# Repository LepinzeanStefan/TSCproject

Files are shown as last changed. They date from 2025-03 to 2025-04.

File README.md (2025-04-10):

# 1. Diagrama Bloc
Diagrama de mai jos arata fluxul de alimentare si conectivitatile principale intre componentele proiectului:
```mermaid
flowchart TD
    %% Blocul de alimentare
    A[USB-C Connector & ESD Protection] 
    B[Li-Po Battery]
    C[Battery Charging Controller<br>MCP73831]
    D[LDO Voltage Regulator]

    %% Blocul de procesare si memorie
    E[ESP32-C6-WROOM-1-N8]
    F[External NOR Flash 64MB]
    G[RTC Module<br>DS3231SN]
    
    %% Blocul de senzori si interfete
    H[Environmental Sensor<br>BME688]
    I[Qwiic / Stemma QT Interface]
    
    %% Blocul de afisare
    J[E-Paper Display Drive Circuit]
    K[E-Paper Display Header<br>Type Selector]
    
    %% Blocul de stocare si management
    L[SD Card]
    M[Voltage Supervisor<br>Reset/Boot Button]

    %% Conexiuni Power Supply
    A --> D
    A --> C
    C --> B
    D --> E

    %% Conexiuni pe placa de dezvoltare
    E --> F
    E --> G
    E --> H
    H --> I

    E --> J
    J --> K

    E --> L
    E --> M
```

# 2. Functionalitate Hardware
===========================

### 2.1 Module, Componente si Senzori

**ESP32-C6-WROOM-1-N8**

- **Rol**: Microcontroler principal, coordoneaza comunicarile (SPI, I2C, UART etc.), citirea senzorilor si controlul perifericelor.

**USB-C Connector & ESD Protection**

- **Rol**: Permite alimentarea prin USB-C si asigura protectie la descarcari electrostatice.

**Battery Charging Controller (MCP73831)**

- **Rol**: Incarca bateria Li-Po si gestioneaza curentul de incarcare.

**Li-Po Battery**

- **Rol**: Sursa de alimentare secundara, permite functionarea sistemului fara USB.

**LDO Voltage Regulator**

- **Rol**: Stabilizeaza tensiunea de 3.3V pentru ESP32-C6 si alte componente.

**External NOR Flash 64MB**

- **Rol**: Memorie suplimentara pentru stocarea datelor si a firmware-ului.

**RTC Module (DS3231SN)**

- **Rol**: Furnizeaza ceas de timp real (Real-Time Clock) cu mare acuratete.
- **Interfata**: I2C, cu suport pentru alarme si detectie a pierderii de tensiune (baterie backup).

**Environmental Sensor (BME688)**

- **Rol**: Masoara temperatura, umiditatea, presiunea si calitatea aerului (VOC).
- **Interfata**: I2C, consum redus in modul standby, integreaza un senzor de gaze.
- **Integrare**: Foloseste Qwiic / Stemma QT pentru conectare rapida.

**E-Paper Display Drive Circuit si Header**

- **Rol**: Genereaza semnalele necesare pentru controlul unui ecran E-Paper si permite selectarea tipului de display.
- **Interfata**: SPI, cu linii de control dedicate (Busy, Reset, DC, CS).

**SD Card**

- **Rol**: Stocare locala de date, fisiere de configurare sau inregistrari pe termen lung.
- **Interfata**: SPI, cu linii separate de chip select.

**Voltage Supervisor + Reset/Boot Button**

- **Rol**: Monitorizeaza tensiunea de alimentare si gestioneaza semnalele de reset si boot pentru ESP32-C6.

### 2.2 Specificatii de Comunicare

- **I2C**: Folosit pentru BME688 si DS3231SN.
- **SPI**: Folosit pentru NOR Flash, E-Paper Display si SD Card.
- **UART**: Disponibil pentru debug sau alte module optionale.
- **Wi-Fi si Bluetooth LE**: Furnizate de ESP32-C6.

### 2.3 Procesare si Calcule de Consum de Energie

- **ESP32-C6**:
  - Consum in mod activ: ~80-240 mA (in functie de sarcina Wi-Fi/BT).
  - Consum in mod sleep: <1 mA (mod deep sleep).

- **BME688**:
  - Consum tipic: ~2.1 uA in sleep, pana la ~3.1 mA in mod activ.

- **NOR Flash**:
  - Consum in citire/scriere: 5-15 mA, in standby: <10 uA.

- **DS3231SN**:
  - Consum: ~150 uA cu backup la baterie.

- **LDO**:
  - Eficienta depinde de diferenta de tensiune (Vin - 3.3V) si curentul total.

In functie de scenariul de utilizare, modul sleep al ESP32-C6 si senzorii in standby reduc semnificativ consumul. Bateria Li-Po poate sustine sistemul pentru ore sau chiar zile, in functie de capacitate si de cat de des se activeaza comunicarile Wi-Fi/BT.

# 3. Pini ESP32-C6 si Motivatii
=============================

In tabelul de mai jos sunt prezentate pinii principali ai ESP32-C6 si rolul lor in proiect:

| Pin ESP32-C6 | Componenta / Rol | Motivatie |
|---|---|---|
| IO14 (SDA) | I2C SDA catre BME688 si DS3231SN | Linia de date pentru I2C |
| IO15 (SCL) | I2C SCL catre BME688 si DS3231SN | Semnal de clock I2C |
| IO6 (MOSI) | SPI MOSI catre NOR Flash, E-Paper, SD Card | Transfer date catre periferice SPI |
| IO7 (MISO) | SPI MISO din NOR Flash, E-Paper, SD Card  | Primire date de la periferice SPI |
| IO8 (SCK) | SPI Clock | Semnal de clock SPI |
| IO9 (CS1) | Chip Select NOR Flash | Control dedicat pentru NOR Flash |
| IO10 (CS2) | Chip Select E-Paper Display | Control dedicat pentru Display |
| IO11 (CS3) | Chip Select SD Card | Control dedicat pentru SD Card |
| IO16, IO17 | UART RX, TX (debug) | Debug serial si programare |
| IO21 | Reset/Boot control | Butoane de reset si boot |

# 4. Bill of Materials (BOM)
=============================

| Component | Buy | Datasheet |
| --- | --- | --- |
| PFMF.050.1 | [Retailer](https://ro.mouser.com/ProductDetail/Schurter/PFMF.050.2?qs=1auRipcfynCums5v1iucSA%3D%3D) |  [Datasheet](https://ro.mouser.com/datasheet/2/358/typ_PFMF-1275918.pdf) |
| USB4110-GF-A | [Retailer](https://ro.mouser.com/ProductDetail/GCT/USB4110-GF-A?qs=KUoIvG%2F9IlYiZvIXQjyJeA%3D%3D) | [Datasheet](https://ro.mouser.com/datasheet/2/837/GCT_USB4110_Product_Drawing___20k_cycles-3455479.pdf) |
| USBLC6-2SC6Y | [Retailer](https://ro.mouser.com/ProductDetail/STMicroelectronics/USBLC6-2SC6Y?qs=gNDSiZmRJS%2FOgDexvXkdow%3D%3D) | [Datasheet](https://ro.mouser.com/datasheet/2/389/usblc6_2sc6y-1852505.pdf) |
| SD0805S020S1R0 | [Retailer](https://ro.mouser.com/ProductDetail/KYOCERA-AVX/SD0805S020S1R0?qs=jCA%252BPfw4LHbpkAoSnwrdjw%3D%3D) | [Datasheet](https://ro.mouser.com/datasheet/2/40/schottky-3165252.pdf) |
| DMG2305UX-7 | [Retailer](https://ro.mouser.com/ProductDetail/Diodes-Incorporated/DMG2305UX-7?qs=L1DZKBg7t5F%2FNBHrjfxC%252Bg%3D%3D) | [Datasheet](https://www.diodes.com/assets/Datasheets/DMG2305UX.pdf) |
| XC6220A331MR-G | [Retailer](https://ro.mouser.com/ProductDetail/Torex-Semiconductor/XC6220A331MR-G?qs=AsjdqWjXhJ8ZSWznL1J0gg%3D%3D) | [Datasheet](https://ro.mouser.com/datasheet/2/760/xc6220-3371556.pdf) |
| Condensator 100 uF TANT | [Retailer](https://ro.mouser.com/ProductDetail/KYOCERA-AVX/TAJW107M010RNJ?qs=Wtp%252Bf%2FAeVqIH8v1VxV%252B1Rg%3D%3D) | [Datasheet](https://ro.mouser.com/datasheet/2/40/TAJ-3165264.pdf) |
| 112A-TAAR-R03_ATTEND | [Retailer](https://www.digikey.ro/en/products/detail/attend-technology/112A-TAAR-R03/17633923) | [Datasheet](https://www.attend.com.tw/data/download/file/112A-TAAR-R03_Spec.pdf)
| ESP32-C6-WROOM-1-N8 | [Retailer](https://ro.mouser.com/ProductDetail/Espressif-Systems/ESP32-C6-WROOM-1-N8?qs=8Wlm6%252BaMh8ST02Gmwp74cw%3D%3D) | [Datasheet](https://ro.mouser.com/datasheet/2/891/Espressif_ESP32_C6_WROOM_1__Datasheet_V0_1_PRELIMI-3239987.pdf) |
| MCP73831 | [Retailer](https://ro.mouser.com/ProductDetail/Microchip-Technology/MCP73831T-2ACI-OT?qs=yUQqVecv4qvbBQBGbHx0Mw%3D%3D) | [Datasheet](https://ro.mouser.com/datasheet/2/268/MCP73831_Family_Data_Sheet_DS20001984H-3441711.pdf) |
| CHG_LED | [Retailer](https://store.comet.srl.ro/Catalogue/Product/40478/) | [Datasheet](https://www.snapeda.com/parts/KP-1608SURCK/Kingbright/datasheet/) |
| SI1308EDL-T1-GE3 | [Retailer](https://ro.mouser.com/ProductDetail/Vishay-Semiconductors/SI1308EDL-T1-GE3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) | [Datasheet](https://www.vishay.com/doc?63399) |
| MBR0530 | [Retailer](https://ro.mouser.com/ProductDetail/Micro-Commercial-Components-MCC/MBR0530-T?qs=9VyI4qLX4NTSXkb9ynzJnA%3D%3D) | [Datasheet](https://ro.mouser.com/datasheet/2/258/mcc_mbr0520~mbr0560sod123-1179695.pdf) |
| L1 | [Retailer](https://ro.mouser.com/ProductDetail/Wurth-Elektronik/744043680?qs=PGXP4M47uW6VkZq%252BkzjrHA%3D%3D) | [Datasheet](https://www.we-online.com/components/products/datasheet/744043680.pdf) |
| FH34SRJ-24S-0.5SH_99_ | [Retailer](https://ro.mouser.com/ProductDetail/Hirose-Connector/FH34SRJ-24S-0.5SH99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) | [Datasheet](https://ro.mouser.com/datasheet/2/185/FH34SRJ_24S_0_5SH_99__CL0580_1255_6_99_2DDrawing_0-1615044.pdf) |
| BME688 | [Retailer](https://ro.mouser.com/ProductDetail/Bosch-Sensortec/BME688?qs=IS%252B4QmGtzzqQoVDscqwx3A%3D%3D) | [Datasheet](https://ro.mouser.com/datasheet/2/783/bst_bme688_fl000-2307034.pdf) |
| BD5229G-TR | [Retailer](https://ro.mouser.com/ProductDetail/ROHM-Semiconductor/BD5229G-TR?qs=4kLU8WoGk0vvnhrrYwdszw%3D%3D) | [Datasheet](https://fscdn.rohm.com/en/products/databook/datasheet/ic/power/voltage_detector/bd52xxg-e.pdf) |
| Button | [Retailer](https://ro.mouser.com/ProductDetail/CK/KMR221GULCLFS?qs=u2NJ%252B70r0goBXaNk7IrU0Q%3D%3D) | [Datasheet](https://www.ckswitches.com/media/1479/kmr2.pdf) |
| MAX17048G+T10 | [Retailer](https://ro.mouser.com/ProductDetail/Analog-Devices-Maxim-Integrated/MAX17048G%2bT10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) | [Datasheet](https://ro.mouser.com/datasheet/2/609/MAX17048_MAX17049-3469099.pdf) |
| W25Q512JVEIQ | [Retailer](https://ro.mouser.com/ProductDetail/Winbond/W25Q512JVEIQ?qs=l7cgNqFNU1jw6svr3at6tA%3D%3D) | [Datasheet](https://ro.mouser.com/datasheet/2/949/Winbond_W25Q512JV_Datasheet-3240039.pdf) |
| PGB1010603MR | [Retailer](https://ro.mouser.com/ProductDetail/Littelfuse/PGB1010603MRHF?qs=KvZd0dN2Zg%2FuIq6icj%252BGKA%3D%3D) | [Datasheet](https://www.littelfuse.com/media?itemid=8a337998-d54d-466b-be4e-dc5bcd1f9321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) |
| QWIIC_RIGHT_ANGLE | [Retailer](https://ro.mouser.com/ProductDetail/GCT/USB4110-GF-A?qs=KUoIvG%2F9IlYiZvIXQjyJeA%3D%3D) | [Datasheet](https://ro.mouser.com/datasheet/2/837/GCT_USB4110_Product_Drawing___20k_cycles-3455479.pdf) |
| DS3231SN# | [Retailer](https://ro.mouser.com/ProductDetail/Analog-Devices-Maxim-Integrated/DS3231SN?qs=ffX8NcjNb2RmKAb9wAk9Ug%3D%3D) | [Datasheet](https://ro.mouser.com/datasheet/2/609/DS3231-3421123.pdf) |
| CPH3225A C10_SUPERCAP | [Retailer](https://ro.mouser.com/ProductDetail/Seiko-Semiconductors/CPH3225A?qs=3etwrb1wR%252BhUOph6lAO7eg%3D%3D) | [Datasheet](https://ro.mouser.com/datasheet/2/360/Seiko_Instruments_MicroBattery_E_20230330_2024Jan_-3561061.pdf) |
| Condensator 100nF | [Retailer](https://ro.mouser.com/ProductDetail/KYOCERA-AVX/06033G104ZAT2A?qs=NXubJDmysXJMPmHfVo6Z%252BA%3D%3D) | [Datasheet](https://ro.mouser.com/datasheet/2/40/KGM_Y5V-3223189.pdf) |
| Condensator 4.7uF | [Retailer](https://ro.mouser.com/ProductDetail/KYOCERA-AVX/0402ZD475MAT2A?qs=NBFAU1oqP4W4U2PCPHI0sg%3D%3D) | [Datasheet](https://ro.mouser.com/datasheet/2/40/cx5r_KGM-3223198.pdf) |
| Condensator 10uF | [Retailer](https://ro.mouser.com/ProductDetail/Samsung-Electro-Mechanics/CL10A106KQ8NNNL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) | [Datasheet](https://ro.mouser.com/datasheet/2/585/MLCC-1837944.pdf) |
| Condensator 1uF/50V | [Retailer](https://ro.mouser.com/ProductDetail/KYOCERA-AVX/06035D105MAT2A?qs=k4kUdCzLgS5%252BURKe1SOIeQ%3D%3D) | [Datasheet](https://ro.mouser.com/datasheet/2/40/cx5r_KGM-3223198.pdf) |
| Resistor 10K | [Retailer](https://ro.mouser.com/ProductDetail/Vishay-Beyschlag/MCS0402MD1002BE000?qs=17u8i%2FzlE8%2F9BrAaXkMk1w%3D%3D) | [Datasheet](https://www.vishay.com/doc?28952) |
| Resistor 200 | [Retailer](https://ro.mouser.com/ProductDetail/Vishay-Beyschlag/MCS0402MD2000BE100?qs=3SvaY9RawMJNVte4F12%252BZQ%3D%3D) | [Datasheet](https://www.vishay.com/doc?28952) |
| Resistor 100K | [Retailer](https://ro.mouser.com/ProductDetail/Vishay-Beyschlag/MCT0603PD1003DP500?qs=5aG0NVq1C4wWAn8Ei3OpZA%3D%3D) | [Datasheet](https://www.vishay.com/doc?28916) |
| Resistor 2.2 | [Retailer](https://ro.mouser.com/ProductDetail/SEI-Stackpole/RMCF0402FT2R20?qs=IPgv5n7u5QbBgyl0jwhwsA%3D%3D) | [Datasheet](https://ro.mouser.com/datasheet/2/385/SEI_RMCF_RMCP-3077565.pdf) |
| Resistor 5K1| [Retailer](https://www.venkel.com/part/TFCR0603-16W-K-5690FT) | [Datasheet](https://data.venkel.com/documents/tfcr-series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.) |
| Resistor 2K | [Retailer](https://ro.mouser.com/ProductDetail/Vishay-Beyschlag/MCS04020C2001FE000?qs=wTZ%2FFzl837YG0wIkZJJOwQ%3D%3D) | [Datasheet](https://www.vishay.com/doc?28705) |
| Resistor 0.47 | [Retailer](https://ro.mouser.com/ProductDetail/SEI-Stackpole/CSR0402JKR470?qs=IPgv5n7u5QawIB6nBEt8wA%3D%3D) | [Datasheet](https://ro.mouser.com/datasheet/2/385/SEI_CSR_CSRN-3077593.pdf) |
| Resistor 15 | [Retailer](https://ro.mouser.com/ProductDetail/YAGEO/RT0402FRE0715RL?qs=BXCcY9r%252B08DFFpLSkPOIqQ%3D%3D) | [Datasheet](https://ro.mouser.com/datasheet/2/447/PYu_RT_1_to_0_01_RoHS_L_15-3461507.pdf) |

# 5. Alte Informatii Relevante
=============================

### 5.1 Design Log si Randari PCB

**Randari PCB**:

- Exista randari 3D ale PCB-ului care arata pozitionarea componentelor majore: conectorul USB-C, ESP32-C6, senzorii si conectorii.
- Carcasa este proiectata in Fusion 360.

### 5.2 Asezarea Componentelor in Carcasa

- Bateria Li-Po este plasata in jurul PCB-ului pentru a economisi spatiu.
- Conectorii Qwiic / Stemma QT sunt pozitionati in marginea placii pentru a permite atasarea rapida a altor senzori.
- Microcontrolerul ESP36 a fost plasat la marginea PCB-ului pentru a reduce pe cat posibil interferentele la antena. Din acelasi motiv a fost taiat si planul de masa si placa PCB in jurul antenei.

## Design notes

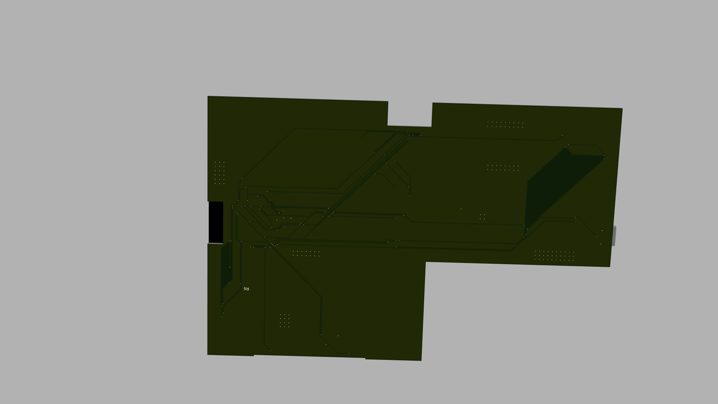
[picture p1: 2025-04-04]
Images/OpenBook v6.png

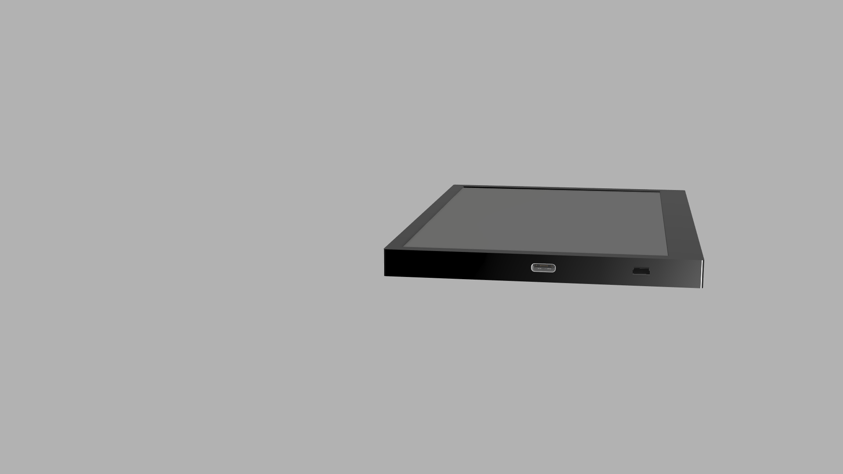
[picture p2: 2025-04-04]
Images/OpenBook Enclosure v7.png

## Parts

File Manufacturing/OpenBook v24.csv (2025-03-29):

Qty | Value | Device | Package | Parts | Description | ARROW_PART_NUMBER | ARROW_PRICE-STOCK | AVAILABILITY | BOOT_BUTTON | CENTROID_NOT_SPECIFIED | CHANGE_BUTTON | CHECK_PRICES | COPYRIGHT | DATASHEET | DESCRIPTION | DIGIKEY_DESCRIPTION | DIGIKEY_PART_NUMBER | DMG2305UX-7 | HEIGHT | LEAD_FREE | MANUFACTURER_NAME | MANUFACTURER_PART_NUMBER | MF | MFR_NAME | MOUSER_PART_NUMBER | MOUSER_PRICE-STOCK | MOUSER_TESTING_PART_NUMBER | MOUSER_TESTING_PRICE-STOCK | MP | MPN | PACKAGE | POPULARITY | PREFIX | PRICE | PROD_ID | PURCHASE-URL | RESET_BUTTON | ROHS | SNAPEDA_LINK | SPICEMODEL | SPICEPREFIX | TEMPERATURE_RANGE_HIGH | TEMPERATURE_RANGE_LOW | TP_SIGNAL_NAME | VALUE
1 |  | SJ | SJ | SJ1 | SMD solder JUMPER |  |  |  |  |  |  |  |  |  |  |  |  |  |  |  |  |  |  |  |  |  |  |  |  |  |  | 3
1 | 0.1uF/50V | EAGLE-LTSPICE_CC0402 | EAGLE-LTSPICE_C0402 | EPD_C5 | CAPACITOR, European symbol |  |  |  |  |  |  |  |  |  |  |  |  |  |  |  |  |  |  |  |  |  |  |  |  |  |  |  |  |  |  |  |  |  |  | NONE | C
1 | 0.47 | ESP32_WROVER_EAGLE-LTSPICE_RR0402 | R0402 | R2 | RESISTOR, European symbol |  |  |  |  |  |  |  |  |  |  |  |  |  |  |  |  |  |  |  |  |  |  |  |  |  |  |  |  |  |  |  |  |  |  | NONE | R
1 | 100K | ESP32_WROVER_EAGLE-LTSPICE_RR0402 | R0402 | R1_PWRUSB | RESISTOR, European symbol |  |  |  |  |  |  |  |  |  |  |  |  |  |  |  |  |  |  |  |  |  |  |  |  |  |  |  |  |  |  |  |  |  |  | NONE | R
8 | 100nF | EAGLE-LTSPICE_CC0402 | EAGLE-LTSPICE_C0402 | C1, C1_SENS, C2_SENS, C4_USB, C6, C9, C10, C_DELAY | CAPACITOR, European symbol |  |  |  |  |  |  |  |  |  |  |  |  |  |  |  |  |  |  |  |  |  |  |  |  |  |  |  |  |  |  |  |  |  |  | NONE | C
1 | 100uF TANT | RCL_CPOL-EUCT3528 | RCL_CT3528 | C3 | POLARIZED CAPACITOR, European symbol |  |  |  |  |  |  |  |  |  |  |  |  |  |  |  |  |  |  |  |  |  |  |  |  |  |  | 0 |  |  |  |  |  |  |  |  | C
16 | 10K | ESP32_WROVER_EAGLE-LTSPICE_RR0402 | R0402 | R1, R1_PINH, R2_PINH, R3, R5, R6, R7, R8, R9, R10, R12, R13, R_BOOT, R_CHANGE, R_CL1, R_RESET | RESISTOR, European symbol |  |  |  |  |  |  |  |  |  |  |  |  |  |  |  |  |  |  |  |  |  |  |  |  |  |  |  |  |  |  |  |  |  |  | NONE | R
1 | 10uF | EAGLE-LTSPICE_CC0402 | EAGLE-LTSPICE_C0402 | C7 | CAPACITOR, European symbol |  |  |  |  |  |  |  |  |  |  |  |  |  |  |  |  |  |  |  |  |  |  |  |  |  |  |  |  |  |  |  |  |  |  | NONE | C
1 | 112A-TAAR-R03_ATTEND | 112A-TAAR-R03_ATTEND | 112ATAARR03ATTEND | J4 | Micro SD Card Socket, Push-Push Type, Top Mount, SMT, H=1.83mm, 10u |  |  |  |  |  |  |  |  |  | Micro SD Card Socket | Push-Push Type | Top Mount | SMT | H=1.83mm | 10u |  |  |  | 1.9mm |  | ATTEND | 112A-TAAR-R03 ATTEND
1 | 15 | ESP32_WROVER_EAGLE-LTSPICE_RR0402 | R0402 | R_CAPACITOR | RESISTOR, European symbol |  |  |  |  |  |  |  |  |  |  |  |  |  |  |  |  |  |  |  |  |  |  |  |  |  |  |  |  |  |  |  |  |  |  | NONE | R
1 | 1uF | EAGLE-LTSPICE_CC0402 | EAGLE-LTSPICE_C0402 | C5 | CAPACITOR, European symbol |  |  |  |  |  |  |  |  |  |  |  |  |  |  |  |  |  |  |  |  |  |  |  |  |  |  |  |  |  |  |  |  |  |  | NONE | C
9 | 1uF/50V | EAGLE-LTSPICE_CC0402 | EAGLE-LTSPICE_C0402 | EPD_C1, EPD_C2, EPD_C6, EPD_C7, EPD_C8, EPD_C9, EPD_C10, EPD_C11, EPD_C12 | CAPACITOR, European symbol |  |  |  |  |  |  |  |  |  |  |  |  |  |  |  |  |  |  |  |  |  |  |  |  |  |  |  |  |  |  |  |  |  |  | NONE | C
1 | 2.2 | ESP32_WROVER_EAGLE-LTSPICE_RR0402 | R0402 | R4 | RESISTOR, European symbol |  |  |  |  |  |  |  |  |  |  |  |  |  |  |  |  |  |  |  |  |  |  |  |  |  |  |  |  |  |  |  |  |  |  | NONE | R
1 | 200 | ESP32_WROVER_EAGLE-LTSPICE_RR0402 | R0402 | R1_BAT | RESISTOR, European symbol |  |  |  |  |  |  |  |  |  |  |  |  |  |  |  |  |  |  |  |  |  |  |  |  |  |  |  |  |  |  |  |  |  |  | NONE | R
2 | 20V/4.2A/52mO/1.4W | ESP32_WROVER_SPARKFUN-DISCRETESEMI_MOSFET_PCH-DMG2305UX-7 | ESP32_WROVER_SPARKFUN-DISCRETESEMI_SOT23-3 | Q1, Q2 | P-channel MOSFETs |  |  |  |  |  |  |  |  |  |  |  |  |  |  |  |  |  |  |  |  |  |  |  |  |  |  |  |  |  | DMG2305UX-7 |  |  |  |  |  |  |  |  |  | 20V/4.2A/52mO/1.4W
1 | 2K | ESP32_WROVER_EAGLE-LTSPICE_RR0402 | R0402 | R2_BAT | RESISTOR, European symbol |  |  |  |  |  |  |  |  |  |  |  |  |  |  |  |  |  |  |  |  |  |  |  |  |  |  |  |  |  |  |  |  |  |  | NONE | R
5 | 4.7uF | EAGLE-LTSPICE_CC0402 | EAGLE-LTSPICE_C0402 | C1_BAT, C1_BAT1, C1_BAT2, C2_BAT, C5_USB | CAPACITOR, European symbol |  |  |  |  |  |  |  |  |  |  |  |  |  |  |  |  |  |  |  |  |  |  |  |  |  |  |  |  |  |  |  |  |  |  | NONE | C
1 | 4.7uF/25V | EAGLE-LTSPICE_CC0402 | EAGLE-LTSPICE_C0402 | C4 | CAPACITOR, European symbol |  |  |  |  |  |  |  |  |  |  |  |  |  |  |  |  |  |  |  |  |  |  |  |  |  |  |  |  |  |  |  |  |  |  | NONE | C
2 | 5k1 | ESP32_WROVER_EAGLE-LTSPICE_RR0402 | R0402 | R2-USB1, R2-USB2 | RESISTOR, European symbol |  |  |  |  |  |  |  |  |  |  |  |  |  |  |  |  |  |  |  |  |  |  |  |  |  |  |  |  |  |  |  |  |  |  | NONE | R
1 | 68uH | 744043680IND_4828-WE-TPC_WRE | IND_4828-WE-TPC_WRE | L1 |  |  |  |  |  |  |  |  | Copyright (C) 2024 Ultra Librarian. All rights reserved. |  |  |  |  |  |  |  |  | 744043680 |  | Wurth Electronics
1 | BD5229G-TR | BD5229G-TR | SOT95P280X125-5N | IC2 | Voltage Detector with Adjustable Delay Time: CMOS processes are utilized to develop high precision, low current consumption CMOS reset ICs that allow arbitrary setting of the delay time. The extensive lineup includes both Nch Open Drain and CMOS output types in a wide range of detection voltages (from 2.3V to 6.0V, in 0.1V steps), enabling selection of the ideal solution based on customer requirements. In addition, the entire series is of course both lead-free and RoHS-compliant. |  |  |  |  |  |  |  |  |  | Voltage Detector with Adjustable Delay Time: CMOS processes are utilized to develop high precision | low current consumption CMOS reset ICs that allow arbitrary setting of the delay time. The extensive lineup includes both Nch Open Drain and CMOS output types in a wide range of detection voltages (from 2.3V to 6.0V | in 0.1V steps) | enabling selection of the ideal solution based on customer requirements. In addition | the entire series is of course both lead-free and RoHS-compliant. |  |  |  | 1.25mm |  | ROHM Semiconductor | BD5229G-TR |  |  | 755-BD5229G-TR | https://www.mouser.co.uk/ProductDetail/ROHM-Semiconductor/BD5229G-TR?qs=4kLU8WoGk0vvnhrrYwdszw%3D%3D
1 | BME688 | ESP32_WROVER_BME680_BME680 | ESP32_WROVER_BME680_PSON80P300X300X100-8N | SENSOR2 | Integrated Environmental Unit |  |  | Unavailable |  |  |  |  |  |  | Integrated Environmental Unit |  |  |  |  |  |  |  | Bosch Sensortec |  |  |  |  |  | BME680 |  | LGA-8 Bosch Tools |  |  | None
3 | BUTTON_CUSYOMV1 | BUTTON_CUSYOMV1 | MYBUTTON | BOOT_BUTTON, CHANGE_BUTTON, RESET_BUTTON
1 | CPH3225A | CPH3225A | CAPCP3225X100N | C10_SUPERCAP | Cap 0.011F 3.3V 1210 Flat Check availability |  |  | Not in stock |  |  |  | https://www.snapeda.com/parts/CPH3225A/Seiko+Instruments/view-part/?ref=eda |  |  | 11 mF (EDLC) Supercapacitor 3.3 V 1210 (3225 Metric) - - |  |  |  |  |  |  |  | Seiko Instruments |  |  |  |  |  | CPH3225A |  | 1210 Seiko |  |  | None |  | https://www.snapeda.com/api/url_track_click_mouser/?unipart_id=562593&manufacturer=Seiko Instruments&part_name=CPH3225A&search_term=None |  |  | https://www.snapeda.com/parts/CPH3225A/Seiko+Instruments/view-part/?ref=snap
1 | DS3231SN# | DS3231SN# | SOIC127P1032X265-16N | U3 | Real Time Clock Serial 16-Pin SOIC W T/R Check availability |  |  | In Stock |  |  |  | https://www.snapeda.com/parts/DS3231SN%23/Analog+Devices/view-part/?ref=eda |  |  | Extremely Accurate I²C-Integrated RTC/TCXO/Crystal |  |  |  |  |  |  |  | Analog Devices |  |  |  |  |  | DS3231SN# |  | SOIC-16 Maxim |  |  | None |  | https://www.snapeda.com/api/url_track_click_mouser/?unipart_id=99048&manufacturer=Analog Devices&part_name=DS3231SN#&search_term=None |  |  | https://www.snapeda.com/parts/DS3231SN%23/Analog+Devices/view-part/?ref=snap
1 | ESP32-C6-WROOM-1-N8 | ESP32-C6-WROOM-1-N8 | XCVR_ESP32-C6-WROOM-1-N8 | U1 | Check availability |  |  | In Stock |  |  |  | https://www.snapeda.com/parts/ESP32-C6-WROOM-1-N8/Espressif+Systems/view-part/?ref=eda |  |  | Multiprotocol Modules ESP32-C6 module | Wi-Fi 6 in 2.4 GHz band | Bluetooth 5 | Zigbee 3.0 and Thread. ESP34-WROOM Compatible - ENGINEERING SAMPLE |  |  |  |  |  |  |  | Espressif Systems |  |  |  |  |  | ESP32-C6-WROOM-1-N8 |  | None |  |  | None |  |  |  |  | https://www.snapeda.com/parts/ESP32-C6-WROOM-1-N8/Espressif+Systems/view-part/?ref=snap
1 | ESP32C6_VARISTORCN1812 | ESP32C6_VARISTORCN1812 | ESP32C6_VARISTOR_CT/CN1812 | PFMF.050.1 | VARISTOR |  |  |  |  |  |  |  |  |  |  |  |  |  |  |  |  |  |  |  |  |  |  |  |  |  |  | 0
2 | ESP32_WROVER_AVX---SD0805S020S1R0_AVX_SD0805S020S1R0_0_0AVX_SD0805S020S1R0_0_0 | ESP32_WROVER_AVX---SD0805S020S1R0_AVX_SD0805S020S1R0_0_0AVX_SD0805S020S1R0_0_0 | ESP32_WROVER_AVX---SD0805S020S1R0_AVX_SD0805S020S1R0_0 | D2, D12 | Schottky Barrier Rectifier Diode |  |  |  |  | No |  |  |  | http://datasheets.avx.com/schottky.pdf |  | DIODE SCHOTTKY 20V 1A 0805 | 478-7800-1-ND |  |  | yes |  |  | AVX |  | 581-SD0805S020S1R0 |  |  |  |  |  | 0805 (2012 metric) |  | D |  |  |  |  | yes |  |  |  | +125°C | -55°C
1 | ESP32_WROVER_SPARKFUN-IC-POWER_MCP73831 | ESP32_WROVER_SPARKFUN-IC-POWER_MCP73831 | ESP32_WROVER_SPARKFUN-IC-POWER_SOT23-5 | MCP73831 | MCP73831T Li-Ion, Li-Pol Controller |  |  |  |  |  |  |  |  |  |  |  |  |  |  |  |  |  |  |  |  |  |  |  |  |  |  |  |  |  | IC-09995
1 | FH34SRJ-24S-0.5SH_99_ | FH34SRJ-24S-0.5SH_99_ | FH34SRJ24S05SH99 | J1 | (0.50mm) Surface Mount, Right Angle |  |  |  |  |  |  |  |  |  | 24 Position FFC | FPC Connector Contacts | (0.50mm) Surface Mount | Right Angle |  |  |  | 1.1mm |  | Hirose | FH34SRJ-24S-0.5SH(99) |  |  | 798-FH34SRJ24S05SH99 | https://www.mouser.co.uk/ProductDetail/Hirose-Connector/FH34SRJ-24S-0.5SH99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
1 | LG R971 | ADAFRUIT_LEDCHIP-LED0603 | ADAFRUIT_CHIP-LED0603 | CHG_LED | LED
1 | MAX17048G+T10 | MAX17048G+T10 | SON50P200X200X80-9N | U4 | Check availability |  |  | In Stock |  |  |  | https://www.snapeda.com/parts/MAX17048G+T10/Analog+Devices/view-part/?ref=eda |  |  | 3µA 1-Cell/2-Cell Fuel Gauge with ModelGauge |  |  |  |  |  |  |  | Analog Devices |  |  |  |  |  | MAX17048G+T10 |  | TDFN-8 Maxim |  |  | None |  | https://www.snapeda.com/api/url_track_click_mouser/?unipart_id=329239&manufacturer=Analog Devices&part_name=MAX17048G+T10&search_term=None |  |  | https://www.snapeda.com/parts/MAX17048G+T10/Analog+Devices/view-part/?ref=snap
3 | MBR0530 | MBR0530 | SOD3716X135N | D3, D4, D5 | ON SEMICONDUCTOR - MBR0530 - DIODE, SCHOTTKY, 0.5A, 30V, SOD-123 |  |  | In Stock |  |  |  | https://www.snapeda.com/parts/MBR0530/Onsemi/view-part/?ref=eda |  |  | Diode Schottky 30 V 500mA Surface Mount SOD-123 |  |  |  |  |  |  |  | ON Semiconductor |  |  |  |  |  | MBR0530 |  | SOD-123-2 ON Semiconductor |  |  | None |  | https://www.snapeda.com/api/url_track_click_mouser/?unipart_id=179458&manufacturer=ON Semiconductor&part_name=MBR0530&search_term=None |  |  | https://www.snapeda.com/parts/MBR0530/Onsemi/view-part/?ref=snap
6 | PGB1010603MR | PGB1010603MR | DIOC1608X36N | D6, D7, D8, D9, D10, D11 | Check availability |  |  | In Stock |  |  |  | https://www.snapeda.com/parts/PGB1010603MR/Littelfuse/view-part/?ref=eda |  |  | 150V (Typ) Clamp - Ipp Tvs Diode Surface Mount 0603 (1608 Metric) |  |  |  |  |  |  |  | Littelfuse Inc. |  |  |  |  |  | PGB1010603MR |  | 0603 Littelfuse Inc. |  |  | None |  | https://www.snapeda.com/api/url_track_click_mouser/?unipart_id=5659453&manufacturer=Littelfuse Inc.&part_name=PGB1010603MR&search_term=None |  |  | https://www.snapeda.com/parts/PGB1010603MR/Littelfuse/view-part/?ref=snap
1 | QWIIC_RIGHT_ANGLE | QWIIC_CONNECTORJS-1MM | JST04_1MM_RA | J3 | SparkFun I2C Standard Qwiic Connector |  |  |  |  |  |  |  |  |  |  |  |  |  |  |  |  |  |  |  |  |  |  |  |  |  |  |  |  |  | CONN-13694 |  |  |  |  |  |  |  |  |  | QWIIC_RIGHT_ANGLE
1 | SAMACSYS_PARTS_USB4110-GF-A | SAMACSYS_PARTS_USB4110-GF-A | SAMACSYS_PARTS_USB4110GFA | J2 | CONN USB 2.0 TYPE-C R/A SMT |  |  |  |  |  |  |  |  |  | CONN USB 2.0 TYPE-C R/A SMT |  |  |  | 3.26mm |  | GCT (GLOBAL CONNECTOR TECHNOLOGY) | USB4110-GF-A |  |  | 640-USB4110-GF-A | https://www.mouser.co.uk/ProductDetail/GCT/USB4110-GF-A?qs=KUoIvG%2F9IlYiZvIXQjyJeA%3D%3D
1 | SI1308EDL-T1-GE3 | SI1308EDL-T1-GE3 | SOT65P210X110-3N | Q4 | MOSFET N-Ch 30V 1.5A TrenchFET SC70 Vishay Si1308EDL-T1-GE3 N-channel MOSFET Transistor, 1.5 A, 30 V, 3-Pin SC-70 |  |  | In Stock |  |  |  | https://www.snapeda.com/parts/SI1308EDL-T1-GE3/Vishay+Siliconix/view-part/?ref=eda |  |  | Si1308EDL-T1-GE3 N-channel MOSFET Transistor | 1.5 A | 30 V | 3-Pin SC-70 | Siliconix / Vishay SI1308EDL-T1-GE3 |  |  |  |  |  |  |  | Vishay Siliconix |  |  |  |  |  | SI1308EDL-T1-GE3 |  | SOT-323 Vishay Semiconductor |  |  | None |  | https://www.snapeda.com/api/url_track_click_mouser/?unipart_id=274603&manufacturer=Vishay Siliconix&part_name=SI1308EDL-T1-GE3&search_term=None |  |  | https://www.snapeda.com/parts/SI1308EDL-T1-GE3/Vishay+Siliconix/view-part/?ref=snap
17 | TPTP20R | TPTP20R | TP20R | 3V3, EPD_3V3, EPD_3V3_C, EPD_BUSY, EPD_CS, EPD_DC, EPD_RST, GND_1, GND_2, INT_RTC, MISO, MOSI, RX, SCK, TX, VBAT, VBUS | Test pad |  |  |  |  |  |  |  |  |  |  |  |  |  |  |  |  |  |  |  |  |  |  |  |  |  |  | 2
1 | USBLC6-2SC6Y | USBLC6-2SC6Y | SOT95P280X145-6N | D1 | Low Cap. ESD Protection Auto SOT-23-6 STMicroelectronics USBLC6-2SC6Y, Dual Uni-Directional TVS Diode Array, 6-Pin SOT-23 |  |  | In Stock |  |  |  | https://www.snapeda.com/parts/USBLC6-2SC6Y/STMicroelectronics/view-part/?ref=eda |  |  | 17V Clamp 5A (8/20µs) Ipp Tvs Diode Surface Mount SOT-23-6 |  |  |  |  |  |  |  | STMicroelectronics |  |  |  |  |  | USBLC6-2SC6Y |  | SOT-23-6 STMicroelectronics |  |  | None |  |  |  |  | https://www.snapeda.com/parts/USBLC6-2SC6Y/STMicroelectronics/view-part/?ref=snap
1 | W25Q512JVEIQ | W25Q512JVEIQ | SON127P600X800X80-9N | U2 | Check availability |  |  | In Stock |  |  |  | https://www.snapeda.com/parts/W25Q512JVEIQ/Winbond+Electronics/view-part/?ref=eda |  |  | FLASH - NOR Memory IC 512Mb (64M x 8) SPI - Quad I/O 133 MHz 8-WSON (8x6) |  |  |  |  |  |  |  | Winbond Electronics |  |  |  |  |  | W25Q512JVEIQ |  | Package |  |  | None |  |  |  |  | https://www.snapeda.com/parts/W25Q512JVEIQ/Winbond+Electronics/view-part/?ref=snap
1 | XC6220A331MR-G | XC6220A331MR-G | SOT95P280X120-5N | IC1 | LDO Voltage Regulators |  |  |  |  |  |  |  |  |  | LDO Voltage Regulators |  |  |  | 1.2mm |  | Torex | XC6220A331MR-G |  |  | 865-XC6220A331MR-G | https://www.mouser.co.uk/ProductDetail/Torex-Semiconductor/XC6220A331MR-G?qs=AsjdqWjXhJ8ZSWznL1J0gg%3D%3D

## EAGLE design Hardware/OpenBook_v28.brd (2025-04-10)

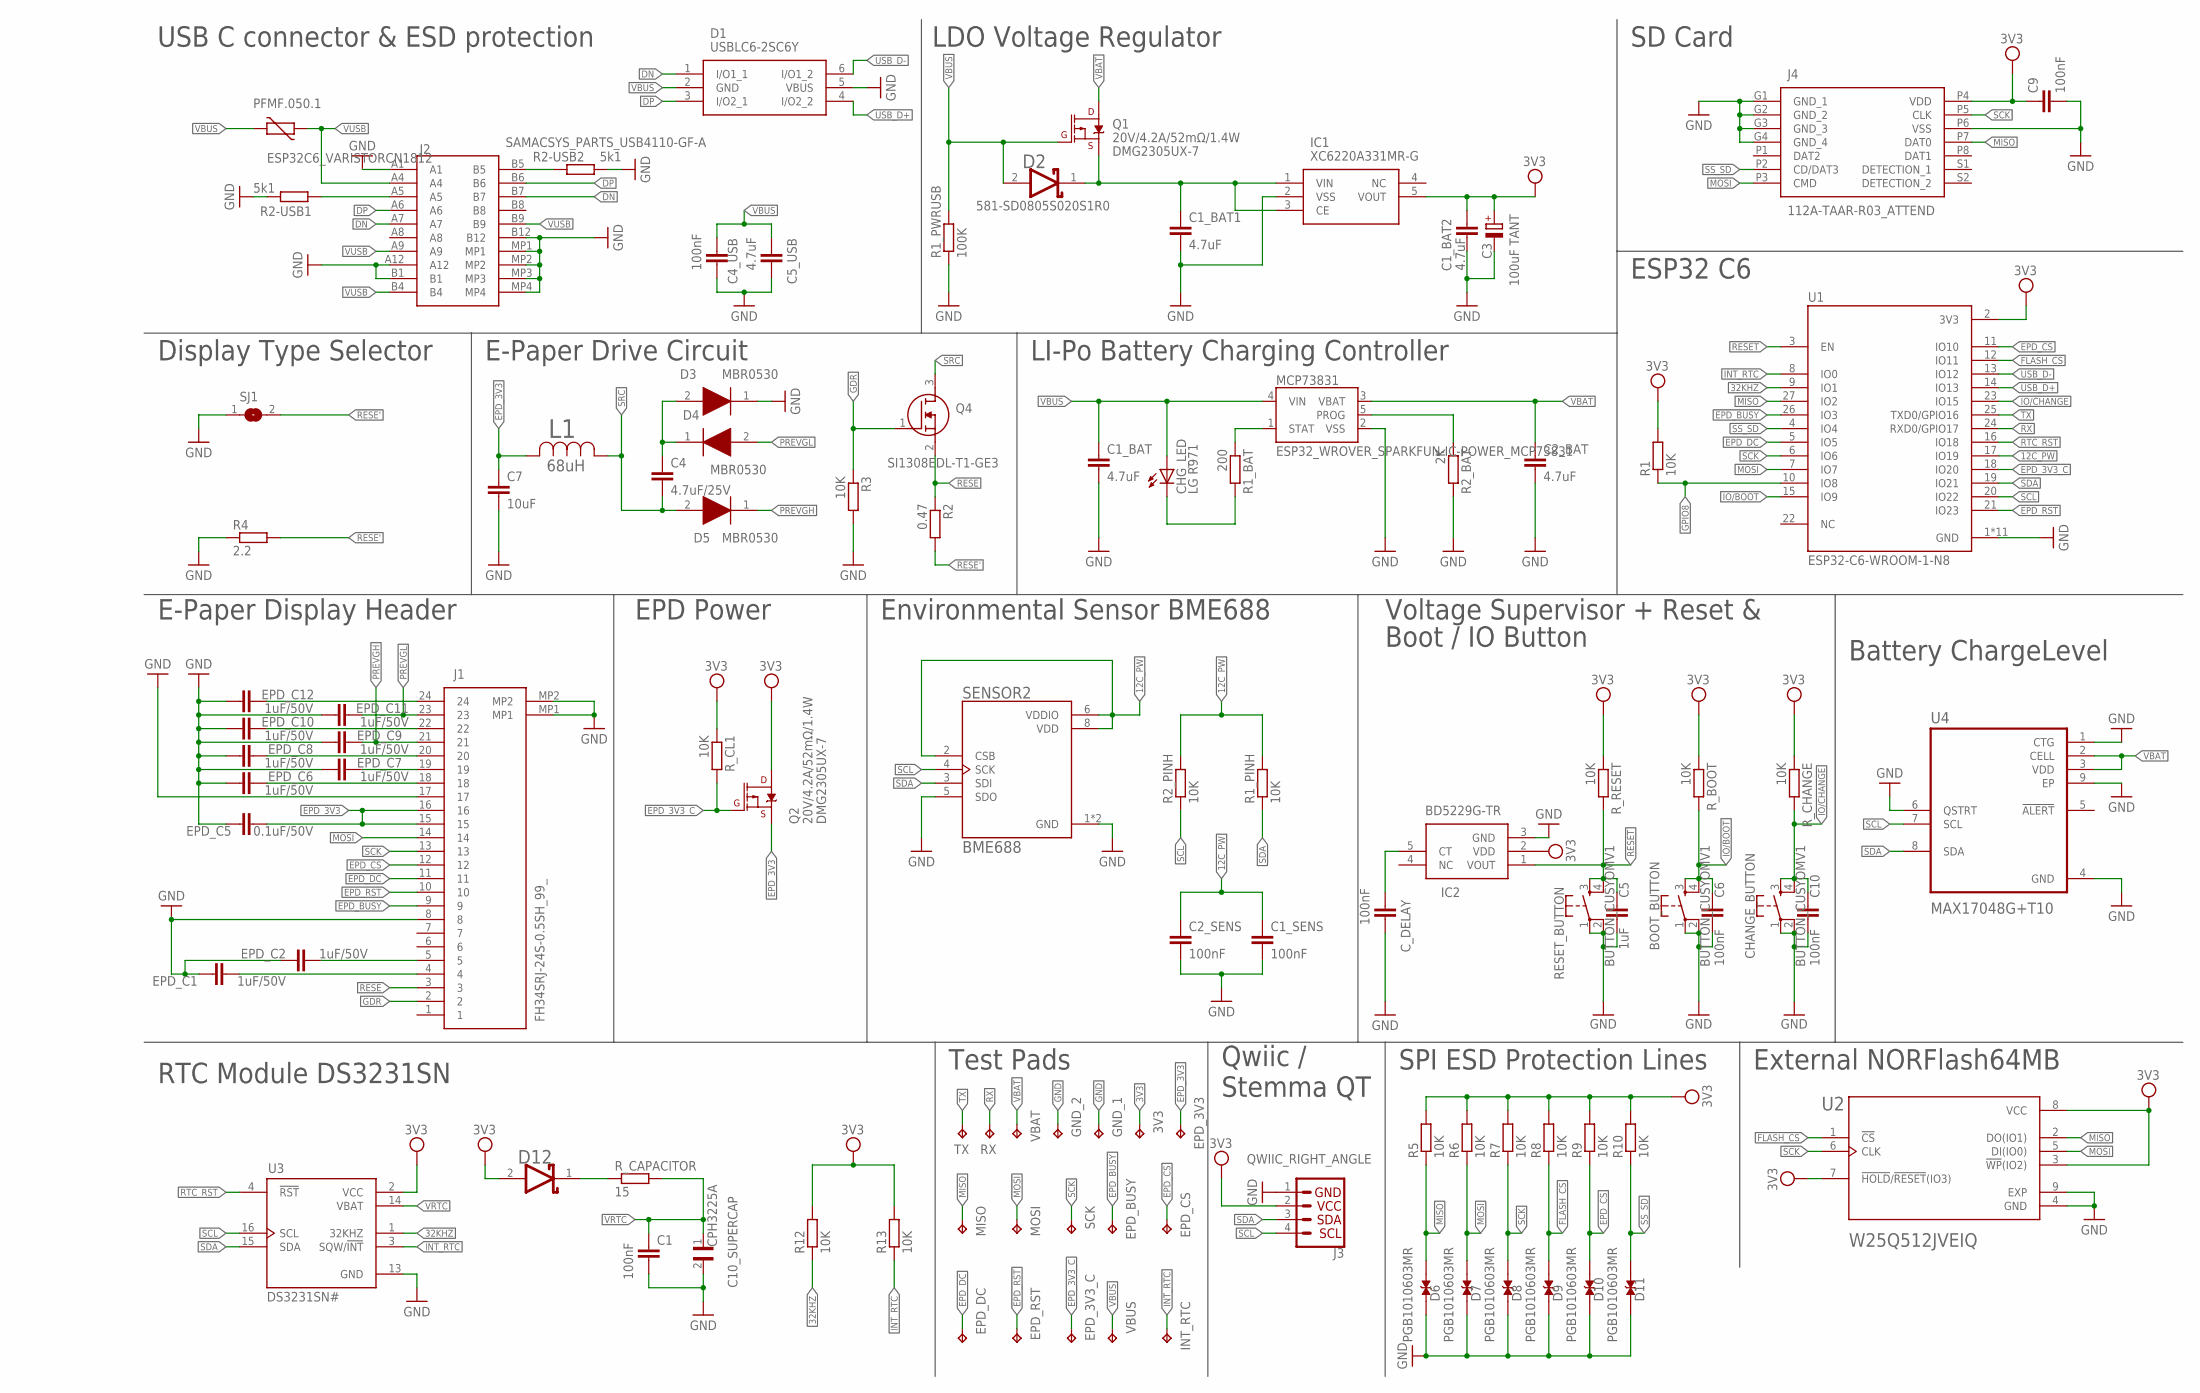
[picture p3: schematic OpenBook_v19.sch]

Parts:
3V3: TPTP20R; TP20R
BOOT_BUTTON: BUTTON_CUSYOMV1; MYBUTTON
C1, C1_SENS, C2_SENS, C4_USB, C6, C9, C10: 100nF; EAGLE-LTSPICE_C0402
C1_BAT, C1_BAT1, C1_BAT2, C2_BAT, C5_USB: 4.7uF; EAGLE-LTSPICE_C0402
C3: 100uF TANT; RCL_CT3528
C4: 4.7uF/25V; EAGLE-LTSPICE_C0402
C5: 1uF; EAGLE-LTSPICE_C0402
C7: 10uF; EAGLE-LTSPICE_C0402
C10_SUPERCAP: CPH3225A; CAPCP3225X100N
CHANGE_BUTTON: BUTTON_CUSYOMV1; MYBUTTON
CHG_LED: LG R971; ADAFRUIT_CHIP-LED0603
C_DELAY: 100nF; EAGLE-LTSPICE_C0402
D1: USBLC6-2SC6Y; SOT95P280X145-6N
D2, D12: ESP32_WROVER_AVX---SD0805S020S1R0_AVX_SD0805S020S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; ESP32_WROVER_AVX---SD0805S020S1R0_AVX_SD0805S020S1R0_0
D3, D4, D5: MBR0530; SOD3716X135N
D6, D7, D8, D9, D10, D11: PGB1010603MR; DIOC1608X36N
EPD_3V3, EPD_3V3_C: TPTP20R; TP20R
EPD_BUSY: TPTP20R; TP20R
EPD_C1, EPD_C2, EPD_C6, EPD_C7, EPD_C8, EPD_C9, EPD_C10, EPD_C11, EPD_C12: 1uF/50V; EAGLE-LTSPICE_C0402
EPD_C5: 0.1uF/50V; EAGLE-LTSPICE_C0402
EPD_CS: TPTP20R; TP20R
EPD_DC: TPTP20R; TP20R
EPD_RST: TPTP20R; TP20R
GND_1, GND_2: TPTP20R; TP20R
IC1: XC6220A331MR-G; SOT95P280X125-5N
IC2: BD5229G-TR; SOT95P280X120-5N
INT_RTC: TPTP20R; TP20R
J1: FH34SRJ-24S-0.5SH_99_; FH34SRJ24S05SH99
J2: SAMACSYS_PARTS_USB4110-GF-A; SAMACSYS_PARTS_USB4110GFA
J3: QWIIC_RIGHT_ANGLE; JST04_1MM_RA
J4: 112A-TAAR-R03_ATTEND; 112ATAARR03ATTEND
L1: 68uH; IND_4828-WE-TPC_WRE
MCP73831: ESP32_WROVER_SPARKFUN-IC-POWER_MCP73831; ESP32_WROVER_SPARKFUN-IC-POWER_SOT23-5
MISO: TPTP20R; TP20R
MOSI: TPTP20R; TP20R
PFMF.050.1: ESP32C6_VARISTORCN1812; ESP32C6_VARISTOR_CT/CN1812
Q1, Q2: 20V/4.2A/52mΩ/1.4W; ESP32_WROVER_SPARKFUN-DISCRETESEMI_SOT23-3
Q4: SI1308EDL-T1-GE3; SOT65P210X110-3N
R1, R1_PINH, R2_PINH, R3, R5, R6, R7, R8, R9, R10, R12, R13: 10K; R0402
R1_BAT: 200; R0402
R1_PWRUSB: 100K; R0402
R2: 0.47; R0402
R2-USB1, R2-USB2: 5k1; R0402
R2_BAT: 2K; R0402
R4: 2.2; R0402
RESET_BUTTON: BUTTON_CUSYOMV1; MYBUTTON
RX: TPTP20R; TP20R
R_BOOT: 10K; R0402
R_CAPACITOR: 15; R0402
R_CHANGE: 10K; R0402
R_CL1: 10K; R0402
R_RESET: 10K; R0402
SCK: TPTP20R; TP20R
SENSOR2: BME688; ESP32_WROVER_BME680_PSON80P300X300X100-8N
SJ1: SJ
TX: TPTP20R; TP20R
U1: ESP32-C6-WROOM-1-N8; XCVR_ESP32-C6-WROOM-1-N8
U2: W25Q512JVEIQ; SON127P600X800X80-9N
U3: DS3231SN#; SOIC127P1032X265-16N
U4: MAX17048G+T10; SON50P200X200X80-9N
VBAT: TPTP20R; TP20R
VBUS: TPTP20R; TP20R

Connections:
3V3: 3V3.TP, C1_BAT2.2, C3.+, C9.1, D12.2 (ANODE), IC1.5 (VOUT), IC2.2 (VDD), J3.2, J4.P4 (VDD), Q2.3 (D), R1.2, R5.2, R6.2, R7.2, R8.2, R9.2, R10.2, R12.2, R13.2, R_BOOT.1, R_CHANGE.1, R_CL1.1, R_RESET.1, U1.2 (3V3), U2.3 (!WP!(IO2)), U2.7 (!HOLD!/!RESET!(IO3)), U2.8 (VCC), U3.2 (VCC)
12C_PW: C1_SENS.1, C2_SENS.1, R1_PINH.2, R2_PINH.2, SENSOR2.2 (CSB), SENSOR2.6 (VDDIO), SENSOR2.8 (VDD), U1.17 (IO19)
32KHZ: R12.1, U1.9 (IO1), U3.1 (32KHZ)
DN: D1.1 (I/O1_1), J2.A7, J2.B7
DP: D1.3 (I/O2_1), J2.A6, J2.B6
EPD_3V3: C7.1, EPD_3V3.TP, EPD_C5.2, J1.15, J1.16, L1.2, Q2.2 (S)
EPD_3V3_C: EPD_3V3_C.TP, Q2.1 (G), R_CL1.2, U1.18 (IO20)
EPD_BUSY: EPD_BUSY.TP, J1.9, U1.26 (IO3)
EPD_CS: D10.2, EPD_CS.TP, J1.12, R9.1, U1.11 (IO10)
EPD_DC: EPD_DC.TP, J1.11, U1.5 (IO5)
EPD_RST: EPD_RST.TP, J1.10, U1.21 (IO23)
FLASH_CS: D9.2, R8.1, U1.12 (IO11), U2.1 (!CS)
GDR: J1.2, Q4.1 (G), R3.1
GND: BOOT_BUTTON.1, BOOT_BUTTON.2, C1.2, C1_BAT.2, C1_BAT1.2, C1_BAT2.1, C1_SENS.2, C2_BAT.2, C2_SENS.2, C3.-, C4_USB.2, C5.2, C5_USB.2, C6.2, C7.2, C9.2, C10.2, C10_SUPERCAP.2, CHANGE_BUTTON.1, CHANGE_BUTTON.2, C_DELAY.2, D1.5 (VBUS), D3.1 (K), D6.1, D7.1, D8.1, D9.1, D10.1, D11.1, EPD_C1.1, EPD_C2.1, EPD_C5.1, EPD_C6.1, EPD_C7.1, EPD_C8.1, EPD_C9.1, EPD_C10.1, EPD_C11.1, EPD_C12.1, GND_1.TP, GND_2.TP, IC1.2 (VSS), IC2.3 (GND), J1.8, J1.17, J1.MP1, J1.MP2, J2.A1, J2.A12, J2.B1, J2.B12, J2.MP1, J2.MP2, J2.MP3, J2.MP4, J3.1, J4.G1 (GND_1), J4.G2 (GND_2), J4.G3 (GND_3), J4.G4 (GND_4), J4.P6 (VSS), MCP73831.2 (VSS), R1_PWRUSB.1, R2-USB1.1, R2-USB2.2, R2_BAT.2, R3.2, R4.1, RESET_BUTTON.1, RESET_BUTTON.2, SENSOR2.1 (GND), SENSOR2.5 (SDO), SENSOR2.7 (GND), SJ1.1, U1.1 (GND), U1.28 (GND), U1.29_1 (GND), U1.29_2 (GND), U1.29_3 (GND), U1.29_4 (GND), U1.29_5 (GND), U1.29_6 (GND), U1.29_7 (GND), U1.29_8 (GND), U1.29_9 (GND), U2.4 (GND), U2.9 (EXP), U3.13 (GND), U4.1 (CTG), U4.4 (GND), U4.6 (QSTRT), U4.9 (EP)
GND1: J2.B5, R2-USB2.1
GPIO8: R1.1, U1.10 (IO8)
INT_RTC: INT_RTC.TP, R13.1, U1.8 (IO0), U3.3 (SQW/!INT)
IO/BOOT: BOOT_BUTTON.3, BOOT_BUTTON.4, C6.1, R_BOOT.2, U1.15 (IO9)
IO/CHANGE: C10.1, CHANGE_BUTTON.3, CHANGE_BUTTON.4, R_CHANGE.2, U1.23 (IO15)
MISO: D6.2, J4.P7 (DAT0), MISO.TP, R5.1, U1.27 (IO2), U2.2 (DO(IO1))
MOSI: D7.2, J1.14, J4.P3 (CMD), MOSI.TP, R6.1, U1.7 (IO7), U2.5 (DI(IO0))
unnamed: J2.A5, R2-USB1.2
unnamed: EPD_C7.2, J1.19
unnamed: MCP73831.1 (STAT), R1_BAT.1
unnamed: C1_BAT1.1, D2.1 (CATHODE), IC1.1 (VIN), IC1.3 (CE), Q1.2 (S)
unnamed: CHG_LED.C, R1_BAT.2
unnamed: EPD_C6.2, J1.18
unnamed: MCP73831.5 (PROG), R2_BAT.1
unnamed: C4.1, D3.2 (A), D4.1 (K)
unnamed: EPD_C8.2, J1.20
unnamed: EPD_C10.2, J1.22
unnamed: EPD_C12.2, J1.24
unnamed: C_DELAY.1, IC2.5 (CT)
unnamed: EPD_C2.2, J1.5
unnamed: EPD_C1.2, J1.4
unnamed: D12.1 (CATHODE), R_CAPACITOR.1
PREVGH: D5.1 (K), EPD_C9.2, J1.21
PREVGL: D4.2 (A), EPD_C11.2, J1.23
RESE: J1.3, Q4.2 (S), R2.1
RESE': R2.2, R4.2, SJ1.2
RESET: C5.1, IC2.1 (VOUT), RESET_BUTTON.3, RESET_BUTTON.4, R_RESET.2, U1.3 (EN)
RTC_RST: U1.16 (IO18), U3.4 (!RST)
RX: RX.TP, U1.24 (RXD0/GPIO17)
SCK: D8.2, J1.13, J4.P5 (CLK), R7.1, SCK.TP, U1.6 (IO6), U2.6 (CLK)
SCL: J3.4, R2_PINH.1, SENSOR2.4 (SCK), U1.20 (IO22), U3.16 (SCL), U4.7 (SCL)
SDA: J3.3, R1_PINH.1, SENSOR2.3 (SDI), U1.19 (IO21), U3.15 (SDA), U4.8 (SDA)
SRC: C4.2, D5.2 (A), L1.1, Q4.3 (D)
SS_SD: D11.2, J4.P2 (CD/DAT3), R10.1, U1.4 (IO4)
TX: TX.TP, U1.25 (TXD0/GPIO16)
USB_D+: D1.4 (I/O2_2), U1.14 (IO13)
USB_D-: D1.6 (I/O1_2), U1.13 (IO12)
VBAT: C2_BAT.1, MCP73831.3 (VBAT), Q1.3 (D), U4.2 (CELL), U4.3 (VDD), VBAT.TP
VBUS: C1_BAT.1, C4_USB.1, C5_USB.1, CHG_LED.A, D1.2 (GND), D2.2 (ANODE), MCP73831.4 (VIN), PFMF.050.1.2, Q1.1 (G), R1_PWRUSB.2, VBUS.TP
VRTC: C1.1, C10_SUPERCAP.1, R_CAPACITOR.2, U3.14 (VBAT)
VUSB: J2.A4, J2.A9, J2.B4, J2.B9, PFMF.050.1.1

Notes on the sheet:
USB C connector & ESD protection
LDO Voltage Regulator
SD Card
ESP32 C6
LI-Po Battery Charging Controller
E-Paper Drive Circuit
Display Type Selector
E-Paper Display Header
EPD Power
Environmental Sensor BME688
Voltage Supervisor + Reset &
Boot / IO Button
Battery ChargeLevel
RTC Module DS3231SN
Test Pads
Qwiic / Stemma QT
SPI ESD Protection Lines
External NORFlash64MB

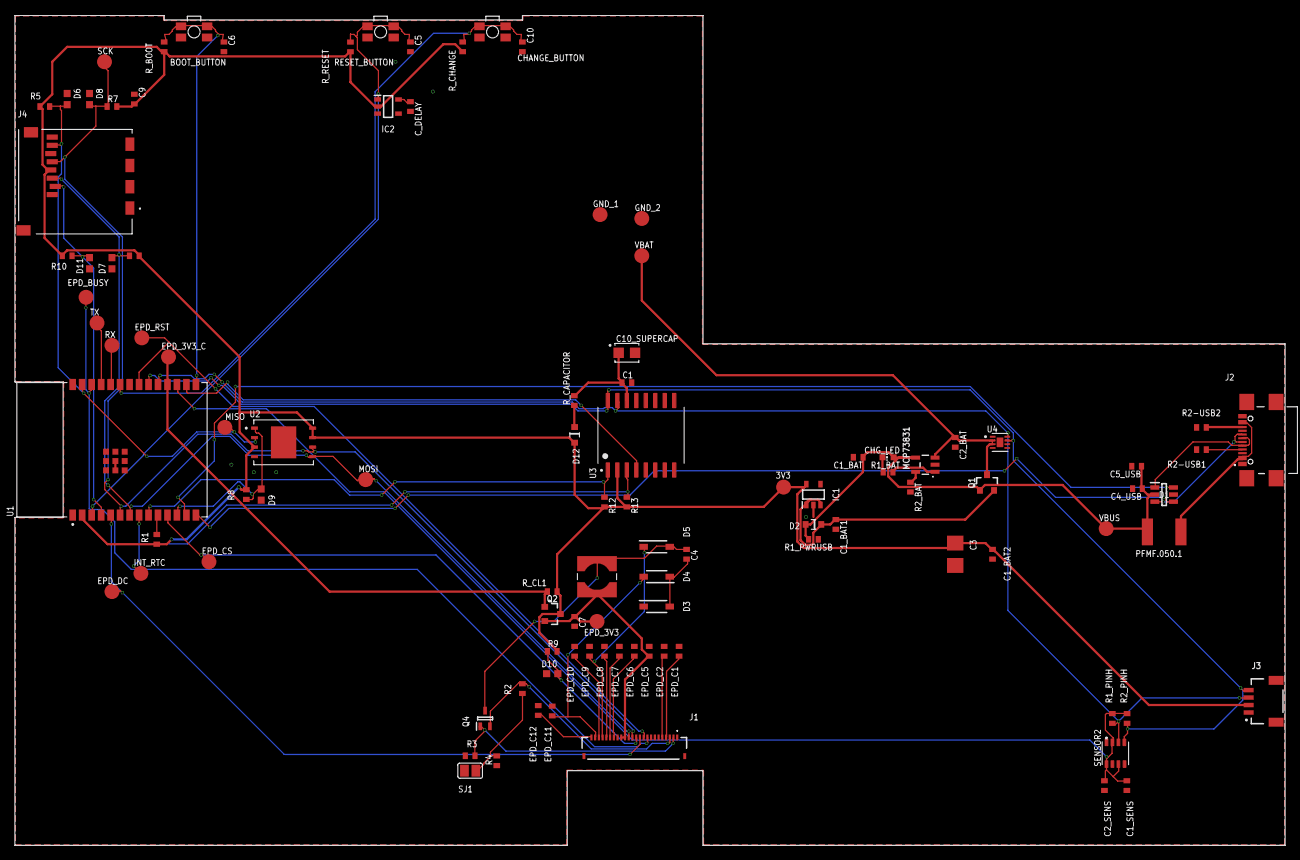
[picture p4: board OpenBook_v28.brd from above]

Board: 2 copper layers, 170.2 x 111.2 mm, 103 parts (0 on the bottom side), 55 nets.

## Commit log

2025-03-27 Finished schematic and board design
    [OpenBook v18.brd, OpenBook_v13.sch]
2025-03-29 Update for schematic and board
    [OpenBook v17.sch, OpenBook v18.brd, OpenBook_v13.sch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]
2025-03-29 Added BOM, PNP and gerbers. Also tried making a block diagram
    [OpenBook v24.csv, PnP_OpenBook v24_front.csv]
2025-03-29 Solved error for mermaid flow chart
2025-04-10 Add the rest of the 3D models, and thin out board
    [OpenBook v17.sch, OpenBook_v19.sch, OpenBook_v24.brd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]
2025-04-10 Update README.md with BOM

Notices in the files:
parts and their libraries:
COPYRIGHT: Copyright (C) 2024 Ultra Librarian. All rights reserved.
